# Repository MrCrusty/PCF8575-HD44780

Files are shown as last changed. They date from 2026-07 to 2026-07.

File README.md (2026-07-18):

# PCF8575-HD44780

8BIT 12C HD44780

# The Kicad 10.x 3D rendered image above shows a PCB designed to use a PCF8575 I2C two port 8bit custom interface for HD44780 LCD's

# A C99 Software driver is provided for STM32 "BlackPill" development board, which should be easily modifed for other MCU's
 
### Hitachi brought the HD44780 to market 40 years ago, at that time I was just turning 40 and in that year my employer complained at the exhorbitant cost of using this display in a digital multimeter that could have quite have easily been an off the peg analogue AVO.

### Today these LCd's are sub £5.00 for a 4 line by 20 character display. However interfacing this LCD in it's native 8bit data bus mode uses to many I/O pins on an embeded MCU design. The solution has been to use I2C interface modules notably the PCF8574 which has become popular as they only require the MCU to use 2 I/O pins (SDA and SCK) to effect communication between the LCD and the MCU. 

image curtosy of "Cricklewood Electronics"

There is to my knowledge only one 8 Bit I2C interface specifically sold to interface directly with the pins of an HD44780LCD display

#### There is a lot of excelent code that suports these I2C port extender modules. There is a trade off with using only an 8 bit extender port which is that the display has to be operated in 4 bit bus mode so that the other 4 bits can be used for the displays control lines. Whilst there is a lot of code for writing to a display in 4 bit mode, there is a very limited amount of code to be found for reading the display memory in 4 bit mode. 

## So is it possible to write to the Hd44780 with I2C in 8 bit mode yes it is not very difficult and a commercial module for doing this is as shown below

image curtosy of "diymore Alice1101983 Store"
  
It uses the MCP23017 chip to provide all the control bits and data bits required to run an hd44780 LCD in 8 bit mode. I have written code for it to run on a STM32 "BlackPill" development board. It works, its fast, and it easily reads the memory from the HD44780 bus. 

## So why design and build my own I2C dual 8 bit port device using the PCF8575 the answer is that the MCP23017 chip needs at least one more I/O pin to be supplied by the MCU in the guise of a reset line, this is essential in my view as the adressing mode of the device can be two diferent options. The other problem for me is that it has far more registers than I need to run the LCD.

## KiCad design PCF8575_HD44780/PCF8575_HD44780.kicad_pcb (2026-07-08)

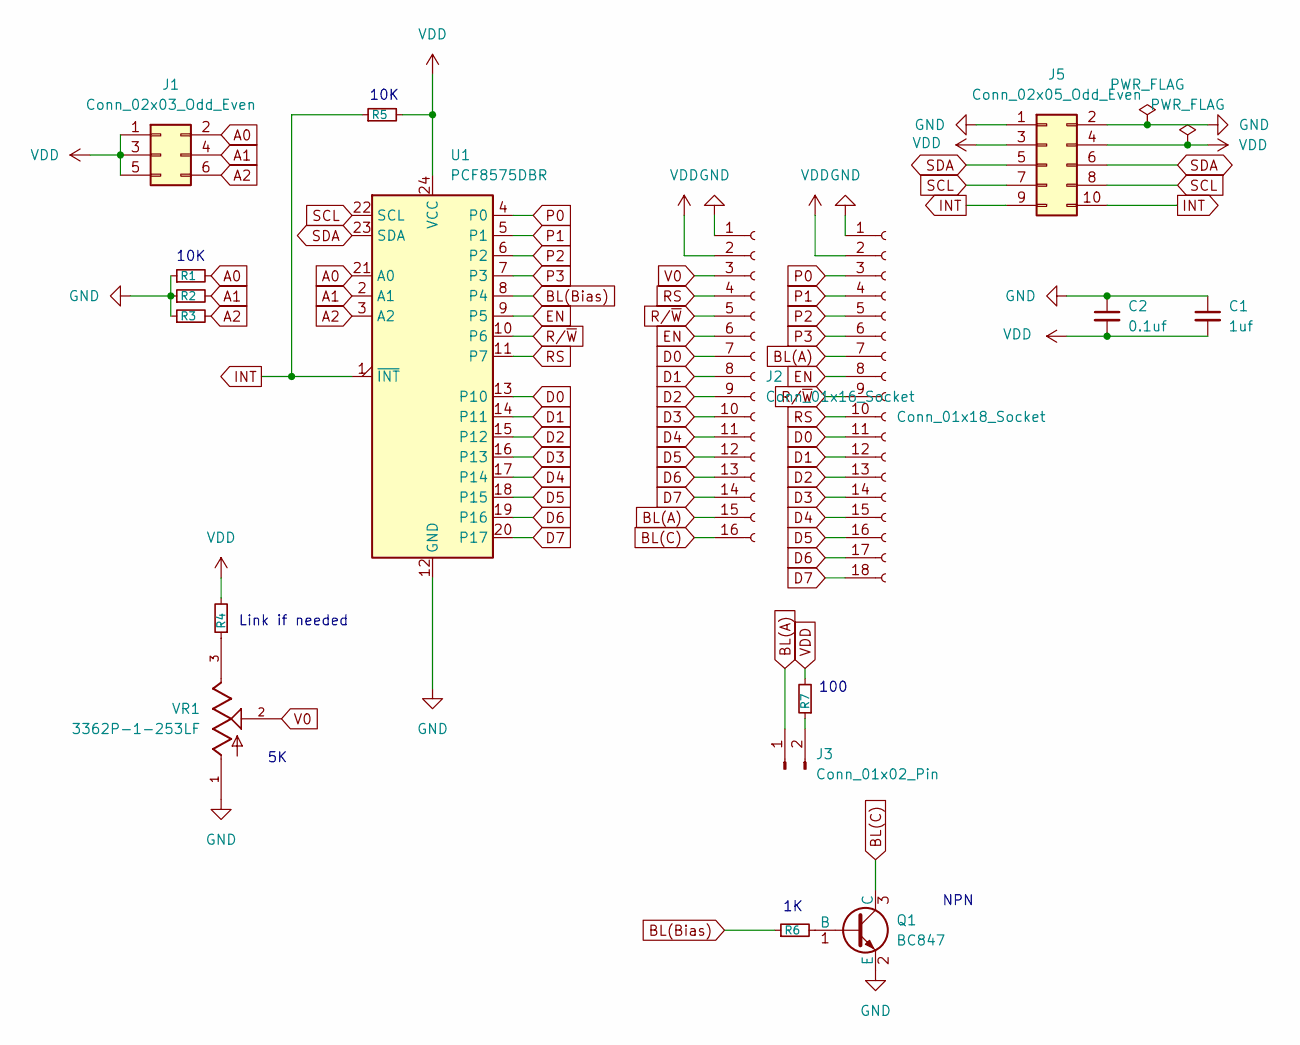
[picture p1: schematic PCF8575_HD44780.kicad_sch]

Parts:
C1: 1uf; C_0805_2012Metric_Pad1.18x1.45mm_HandSolder
C2: 0.1uf; C_0805_2012Metric
J1: Conn_02x03_Odd_Even; PinHeader_2x03_P2.54mm_Vertical
J2: Conn_01x16_Socket; PinHeader_1x16_P2.54mm_Vertical
J3: Conn_01x02_Pin; PinHeader_1x02_P2.54mm_Vertical
J4: Conn_01x18_Socket; PinHeader_1x18_P2.54mm_Vertical
J5: Conn_02x05_Odd_Even; PinSocket_2x05_P2.54mm_Vertical
Q1: BC847; SOT-23
R1, R2, R3, R4, R5, R6, R7: R_Small; R_0805_2012Metric
U1: PCF8575DBR; SSOP-24_5.3x8.2mm_P0.65mm
VR1: 3362P-1-253LF; TRIM_3362P-1-253LF; PARTREV 08/26/10

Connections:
A0: J1.2, R1.2, U1.21 (A0)
A1: J1.4, R2.2, U1.2 (A1)
A2: J1.6, R3.2, U1.3 (A2)
BL(A): J2.15, J3.1, J4.7
BL(Bias): R6.1, U1.8 (P4)
BL(C): J2.16, Q1.3 (C)
D0: J2.7, J4.11, U1.13 (P10)
D1: J2.8, J4.12, U1.14 (P11)
D2: J2.9, J4.13, U1.15 (P12)
D3: J2.10, J4.14, U1.16 (P13)
D4: J2.11, J4.15, U1.17 (P14)
D5: J2.12, J4.16, U1.18 (P15)
D6: J2.13, J4.17, U1.19 (P16)
D7: J2.14, J4.18, U1.20 (P17)
EN: J2.6, J4.8, U1.9 (P5)
GND: C1.1, C2.1, J2.1, J4.1, J5.1, J5.2, Q1.2 (E), R1.1, R2.1, R3.1, U1.12 (GND), VR1.1
INT: J5.9, J5.10, R5.1, U1.1 (~INT)
unnamed: J3.2, R7.1
unnamed: Q1.1 (B), R6.2
unnamed: R4.1, VR1.3
P0: J4.3, U1.4 (P0)
P1: J4.4, U1.5 (P1)
P2: J4.5, U1.6 (P2)
P3: J4.6, U1.7 (P3)
RS: J2.4, J4.10, U1.11 (P7)
R/~W: J2.5, J4.9, U1.10 (P6)
SCL: J5.7, J5.8, U1.22 (SCL)
SDA: J5.5, J5.6, U1.23 (SDA)
V0: J2.3, VR1.2
VDD: C1.2, C2.2, J1.1, J1.3, J1.5, J2.2, J4.2, J5.3, J5.4, R4.2, R5.2, R7.2, U1.24 (VCC)

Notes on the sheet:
100
10K
NPN
Link if needed

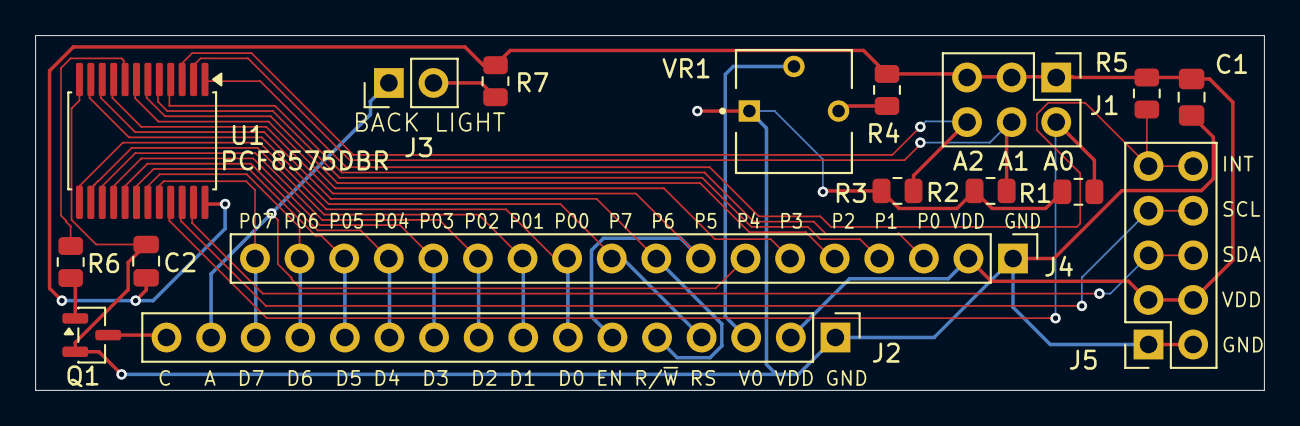
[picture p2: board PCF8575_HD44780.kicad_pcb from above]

Board: 2 copper layers, 70.0 x 20.2 mm, 17 parts (0 on the bottom side), 30 nets.

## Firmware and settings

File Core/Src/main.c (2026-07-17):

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
/* Includes ------------------------------------------------------------------*/
#include "main.h"
#include "i2c.h"
#include "gpio.h"

/* USER CODE BEGIN Includes */
#include "hd44780_12c_8bit.h"
/* USER CODE END Includes */


/* USER CODE BEGIN PV */
char custom_patten_tick[8]={0, 1, 3, 22, 28, 8, 0, 0}; //provides a tick icon for HD44780 display
char custom_patten_x[8]  =  {31,17, 10, 4, 10, 17, 31, 0};

/* USER CODE END PV */

void SystemClock_Config(void);
/**
  * @brief  The application entry point.
  * @retval int
  */
int main(void)
{

  /* MCU Configuration--------------------------------------------------------*/

  /* Reset of all peripherals, Initializes the Flash interface and the Systick. */
  HAL_Init();

  /* Configure the system clock */
  SystemClock_Config();

  /* Initialize all configured peripherals */
  MX_GPIO_Init();
  MX_I2C1_Init();
  /* USER CODE BEGIN 2 */
hd44780_init_8bit(0x21, BACK_LIGHT_ON);
hd44780_custom_char(0x21, 0x01, custom_patten_tick, 8);
hd44780_custom_char(0x21, 0x00, custom_patten_x, 8);
static LineStruct line_char;
uint32_t ticks_taken_start;
uint32_t ticks_taken_finish;
uint32_t ticks_taken;
char Ans[20];
char temp[1] ;
temp[0]= 'H';
uint8_t char_count;
//hd44780_clr_disp(0x21);
hd44780_write_message_at(0x21, "Copy this  line", 0, 0, true);
ticks_taken_start = HAL_GetTick();
line_char = hd44780_read_line_from(0x21, 0, 0, READ_TO_EOL);
ticks_taken_finish = HAL_GetTick();
ticks_taken = ticks_taken_finish - ticks_taken_start;
hd44780_format8_dec(ticks_taken, Ans);
hd44780_write_message_at(0x21, "Read Ms takes ", 1, 0, true);
hd44780_write_message(0x21, Ans);
char_count = line_char.array[20];
ticks_taken_start = HAL_GetTick();
hd44780_write_line_from(0x21,2,0,line_char,  line_char.array[20]);
ticks_taken_finish = HAL_GetTick();
ticks_taken = ticks_taken_finish - ticks_taken_start;
hd44780_format8_dec(ticks_taken, Ans);
hd44780_write_message_at(0x21, "Write Ms takes ", 3, 0, true);
hd44780_write_message(0x21, Ans);
//hd44780_write_bulk_bytes(0x21, line_char.array, 19);
//hd44780_write_character(0x21, 0);
//hd44780_write_character_at(0x21,0x01,0,16,0);
//hd44780_write_character_at(0x21, '1', 0, 1, true);
//hd44780_write_message_at(0x21, "this is a message", 3, 1, true);

//hd44780_write_message_at(0x21, "line 2 text line", 2, 0, true);
//hd44780_write_character(0x21, 0);
//hd44780_read_data(0x20, 3, 0, false);
//temp[0]= hd44780_read_single_byte(0x21, 3, 2);
//hd44780_set_line(0x21, 0, 5, false);
//hd44780_write_bulk_data(0x21, temp, 1);

  /* USER CODE END 2 */

  /* Infinite loop */
  /* USER CODE BEGIN WHILE */
  while (1)
  {
//hd44780_write_message_at(0x21, "LINE 1 TEXT", 1, 2, true);
//HAL_Delay(5000);
//hd44780_set_line(0x21, 1, 2, true);
//HAL_Delay(5000);
  }
  /* USER CODE END 3 */
}

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


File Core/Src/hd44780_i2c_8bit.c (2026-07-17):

/*
 * hd44780_i2c_8bit.c
 *
 *  Created on: 8 Jun 2026
 *      Author: mrcru
 */
#include "hd44780_12c_8bit.h"
int bit_modify(int x, unsigned char position, bool new_state); //local forward declaration

const uint8_t  Line0 = 0x00;
const uint8_t  Line1 = 0x40;
const uint8_t  Line2 = 0x14;
const uint8_t  Line3 = 0x54;
static uint8_t text_count;
static uint8_t text_line;
static LineStruct text_line_0;
static char text_line_1[20];
static char text_line_2[20];
static char text_line_3[20];
const uint8_t DisplayWidth = 20;

typedef struct
	{
		uint8_t chip_type;
		uint8_t device_add;
		uint8_t lines;
		uint8_t characters;
	} I2C_Process_handler;

I2C_Process_handler Interface8575 =
	{
		.chip_type = PCF_8575,
		.device_add = 0x21,
		.lines = 4,
		.characters = 20
	};




/**
 	 *Max number of characters on a 20*4 line screen = 80 elements
 	 *To send in bulk with only the use of device address once
 	 *requires 2 passes .
 	 *Pass 1 is
 	 *Control byte followed by data byte with no enable set in the control byte
 	 *this allows setup time
 	 *Pass 2 is
 	 *Control byte followed by data byte with with enable set in the control byte
 	 *this allows write to happen data byte is the same
 	 *this is so the next control byte and data sent go to the correct 2 registers
*/
char I2C_send_buffer[320];//buffer for HAL I2C functions
_Bool back_light_state;

void hd44780_backlight_on_off(_Bool state)
{
	back_light_state = state;
}


void hd44780_write_instruction(uint8_t device_add,uint8_t HD_data_byte)
{
	uint8_t HD_control_byte =0b00100000;//bit 7 set for instruction, bit 6 set for write, bit 5 set not to enable
	HD_control_byte = bit_modify(HD_control_byte, BL, back_light_state);//setbit 4 for the baclight state
	I2C_send_buffer[0]= HD_control_byte;//put in buffer
	I2C_send_buffer[1]= HD_data_byte;//put in buffer
	HAL_I2C_Master_Transmit( &hi2c1, (device_add <<1), I2C_send_buffer, 2, 200);//activate the write
	HAL_Delay(1);
	HD_control_byte = bit_modify(HD_control_byte, EN, 0);//disable the write
	I2C_send_buffer[0]= HD_control_byte;//send to buffer
	HAL_I2C_Master_Transmit( &hi2c1, (device_add <<1), I2C_send_buffer, 2, 200);//deactivate the write
	HAL_Delay(1);
}

/**
 *	@Brief Writes a block of data byte  to the HD44780  in 8 bit mode.
 *  @Brief This is achieved by sending control bytes separated by data bytes.
 *  @Brief 8575 I2C will roll through its two port registers until a new adress is sent.
  * @Brief PLEASE NOTE CGRAM or DDRAM read/write need  SET_CGRAM_ADDRESS / SET_DDRAM_ADDRESS
  * @Brief prior to calling any memory read / write function
  * @variable (control_byte local variable, holding the HD44780 bits RS,RW,EN and Backlight
  * @variable (bl_state) global variable, used to set baklight bit on each pass of function.
  * @param   (slave_add) hardware address of slave
  * @param  (HD_data[] )used to sequentially load the 8bit data  to the HD44780 data bus.
  * @param int data_count used to extract each element of the message until 0 or null termination reached
  * @param buffer_pos keeps count of the bytes used in the array sent to HAL_I2C master transmit function
  * @retval no return value as yet
  */
void hd44780_write_bulk_bytes(uint8_t device_add, char HD_data[],int str_num)
{
	uint8_t control_byte_no_enable=0b10000000;//bit 7 set for data bit 6 set for write, bit 5 not set for enable
	control_byte_no_enable = bit_modify(control_byte_no_enable, BL, back_light_state);//set bit 4 for the baclight state
	uint8_t control_byte_enable=0b10100000;//bit 7 set for data bit 6 set for write, bit 5 set to enable
	control_byte_enable = bit_modify(control_byte_enable, BL, back_light_state);//setbit 4 for the baclight state
	int data_count = 0;
	uint16_t buffer_pos = 0;
	while(data_count < str_num)//test for length of array reached
		{
			I2C_send_buffer[buffer_pos] = control_byte_enable;//set not enabled
			buffer_pos ++;// inc the buffer count to next array element
			I2C_send_buffer[buffer_pos]= HD_data[data_count];//add the data register value
			buffer_pos ++;// inc the buffer count to next array element
			//first pass done to set up data and control without hd44780 enable
			I2C_send_buffer[buffer_pos] = control_byte_no_enable;//set so enabled
			buffer_pos++;//set next buffer location
			I2C_send_buffer[buffer_pos]= HD_data[data_count];//add the data register value to remain same while write enabled
			buffer_pos++;//set next buffer location
			data_count++; // set to read the next data byte
		}
	HAL_I2C_Master_Transmit( &hi2c1, (device_add<<1), I2C_send_buffer,buffer_pos,200);//deactivate the write
}

/**
 *  Writes a single data byte  to the HD44780  in 8 bit mode.
  * @variable (control_byte local variable, holding the HD44780 bits RS,RW,EN and Backlight
  * @variable (bl_state) global variable, used to set baklight bit on each pass of function.
  * @param   (slave_add) hardware address of slave
  * @param  (HD_data[] )used to sequentially load the 8bit data  to the HD44780 data bus.
  * @retval no return value as yet
  */
/*
void hd44780_write_single_byte(uint8_t device_add, uint8_t HD_data_byte)
{


	uint8_t HD_control_byte =0b10100000;//bit 7 set for data bit 6 set for write, bit 5 set not to enable
	HD_control_byte = bit_modify(HD_control_byte, BL, back_light_state);//setbit 4 for the baclight state
	I2C_send_buffer[0]= HD_control_byte;//put in buffer
	I2C_send_buffer[1]= HD_data_byte;//put in buffer
	HAL_I2C_Master_Transmit(&hi2c1, (device_add <<1), I2C_send_buffer, 2, 200);//activate the write
	HD_control_byte = bit_modify(HD_control_byte, EN, 0);//disable the write
	I2C_send_buffer[0]= HD_control_byte;//send to buffer
	HAL_I2C_Master_Transmit( &hi2c1, (device_add <<1), I2C_send_buffer, 2, 200);//deactivate the write


}
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

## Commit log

2026-07-11 Enhance README with hardware and software details
    Updated README to include details about the hardware PCB and software driver for STM32 'BlackPill' board. Added images and clarified the functionality of the PCF8575 I2C interface.
2026-07-18 Revise README for clarity and detail improvements
    Updated README to clarify the hardware and software details for the PCF8575 I2C interface with HD44780 LCDs, including improvements to grammar and clarity.
2026-07-18 Update README with I2C and HD44780 details
    Added information about using I2C with HD44780 in 8-bit mode and included an image reference.
2026-07-18 Update README with custom I2C device explanation
    Added explanation for designing a custom I2C dual 8-bit port device using the PCF8575 due to MCP23017 limitations.

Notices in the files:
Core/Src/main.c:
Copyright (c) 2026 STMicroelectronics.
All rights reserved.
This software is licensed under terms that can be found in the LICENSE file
